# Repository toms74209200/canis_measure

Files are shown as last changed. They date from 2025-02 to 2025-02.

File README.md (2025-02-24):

<h1 style="text-align: center; margin-bottom: 4rem;">
<p style="font-size: 3rem;">Canis Measure</p>
Air Quality Monitor
</h1>

https://github.com/user-attachments/assets/3cffaff6-82ad-4612-b39e-0665e6a29b27

## Features

### Temperature and Humidity

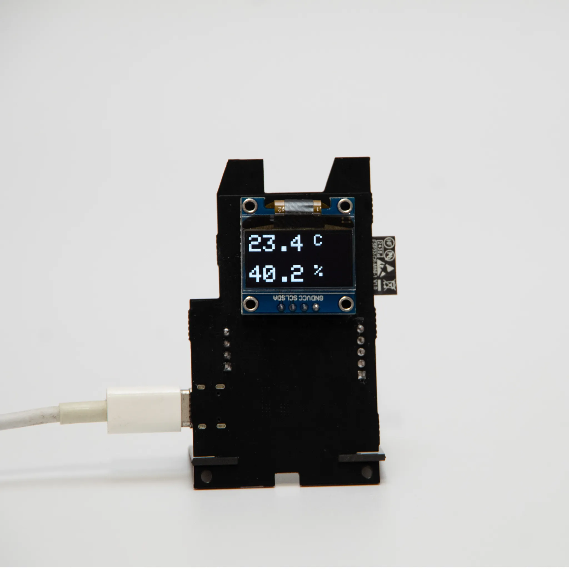
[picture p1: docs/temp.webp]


Temperature and humidity sensor is the SHT30.

### Pressure, CO2

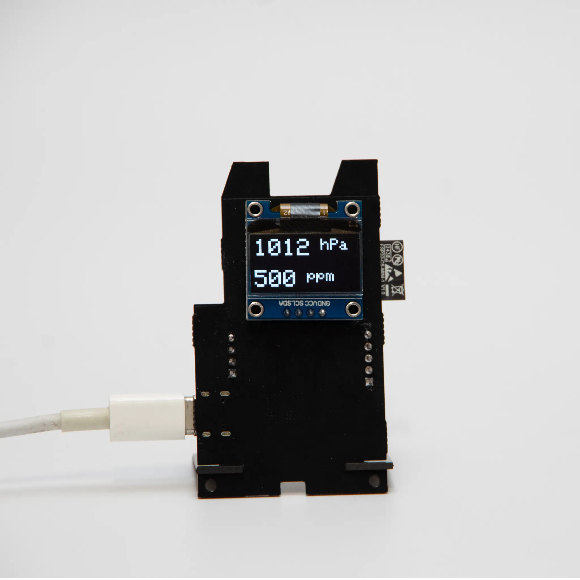
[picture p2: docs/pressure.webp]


Pressure sensor is the BMP280, CO2 sensor is the MH-Z19B.

## Specification

- [Espressif ESP32-C6](https://www.espressif.com/en/products/socs/esp32-c6)
- [Sensirion SHT30](https://sensirion.com/products/catalog/SHT30-DIS-B)
- [BOSCH BMP280](https://www.bosch-sensortec.com/products/environmental-sensors/pressure-sensors/bmp280/)
- [Winsen MH-Z19B](https://www.winsen-sensor.com/product/mh-z19b.html)
- 128x64 OLED display(SSD1306)

### Schematic

https://github.com/toms74209200/canis_measure/blob/master/pcb/EAQM-250201.pdf

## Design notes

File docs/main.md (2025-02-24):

<h1 style="text-align: center; margin-bottom: 4rem;">
<p style="font-size: 3rem;">Canis Measure</p>
Air Quality Monitor
</h1>

<video width="100%" height="auto" autoplay loop muted style="background-color: transparent;">
  <source src="canis_measure_face_movie.mp4" type="video/mp4">
  Your browser does not support the video tag.
</video>

## Features

### Temperature and Humidity



Temperature and humidity sensor is the SHT30.

### Pressure, CO2



Pressure sensor is the BMP280, CO2 sensor is the MH-Z19B.

## Specification

- [Espressif ESP32-C6](https://www.espressif.com/en/products/socs/esp32-c6)
- [Sensirion SHT30](https://sensirion.com/products/catalog/SHT30-DIS-B)
- [BOSCH BMP280](https://www.bosch-sensortec.com/products/environmental-sensors/pressure-sensors/bmp280/)
- [Winsen MH-Z19B](https://www.winsen-sensor.com/product/mh-z19b.html)
- 128x64 OLED display(SSD1306)

### Schematic

https://github.com/toms74209200/canis_measure/blob/master/pcb/EAQM-250201.pdf

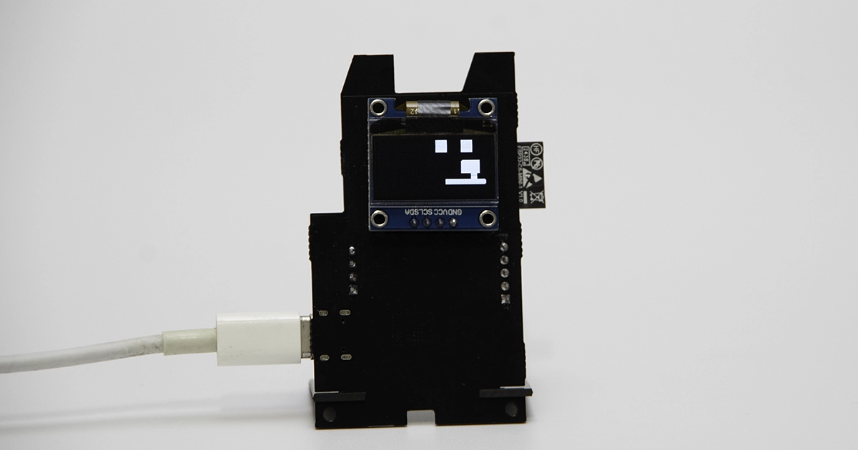
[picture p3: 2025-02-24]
docs/ogp.webp

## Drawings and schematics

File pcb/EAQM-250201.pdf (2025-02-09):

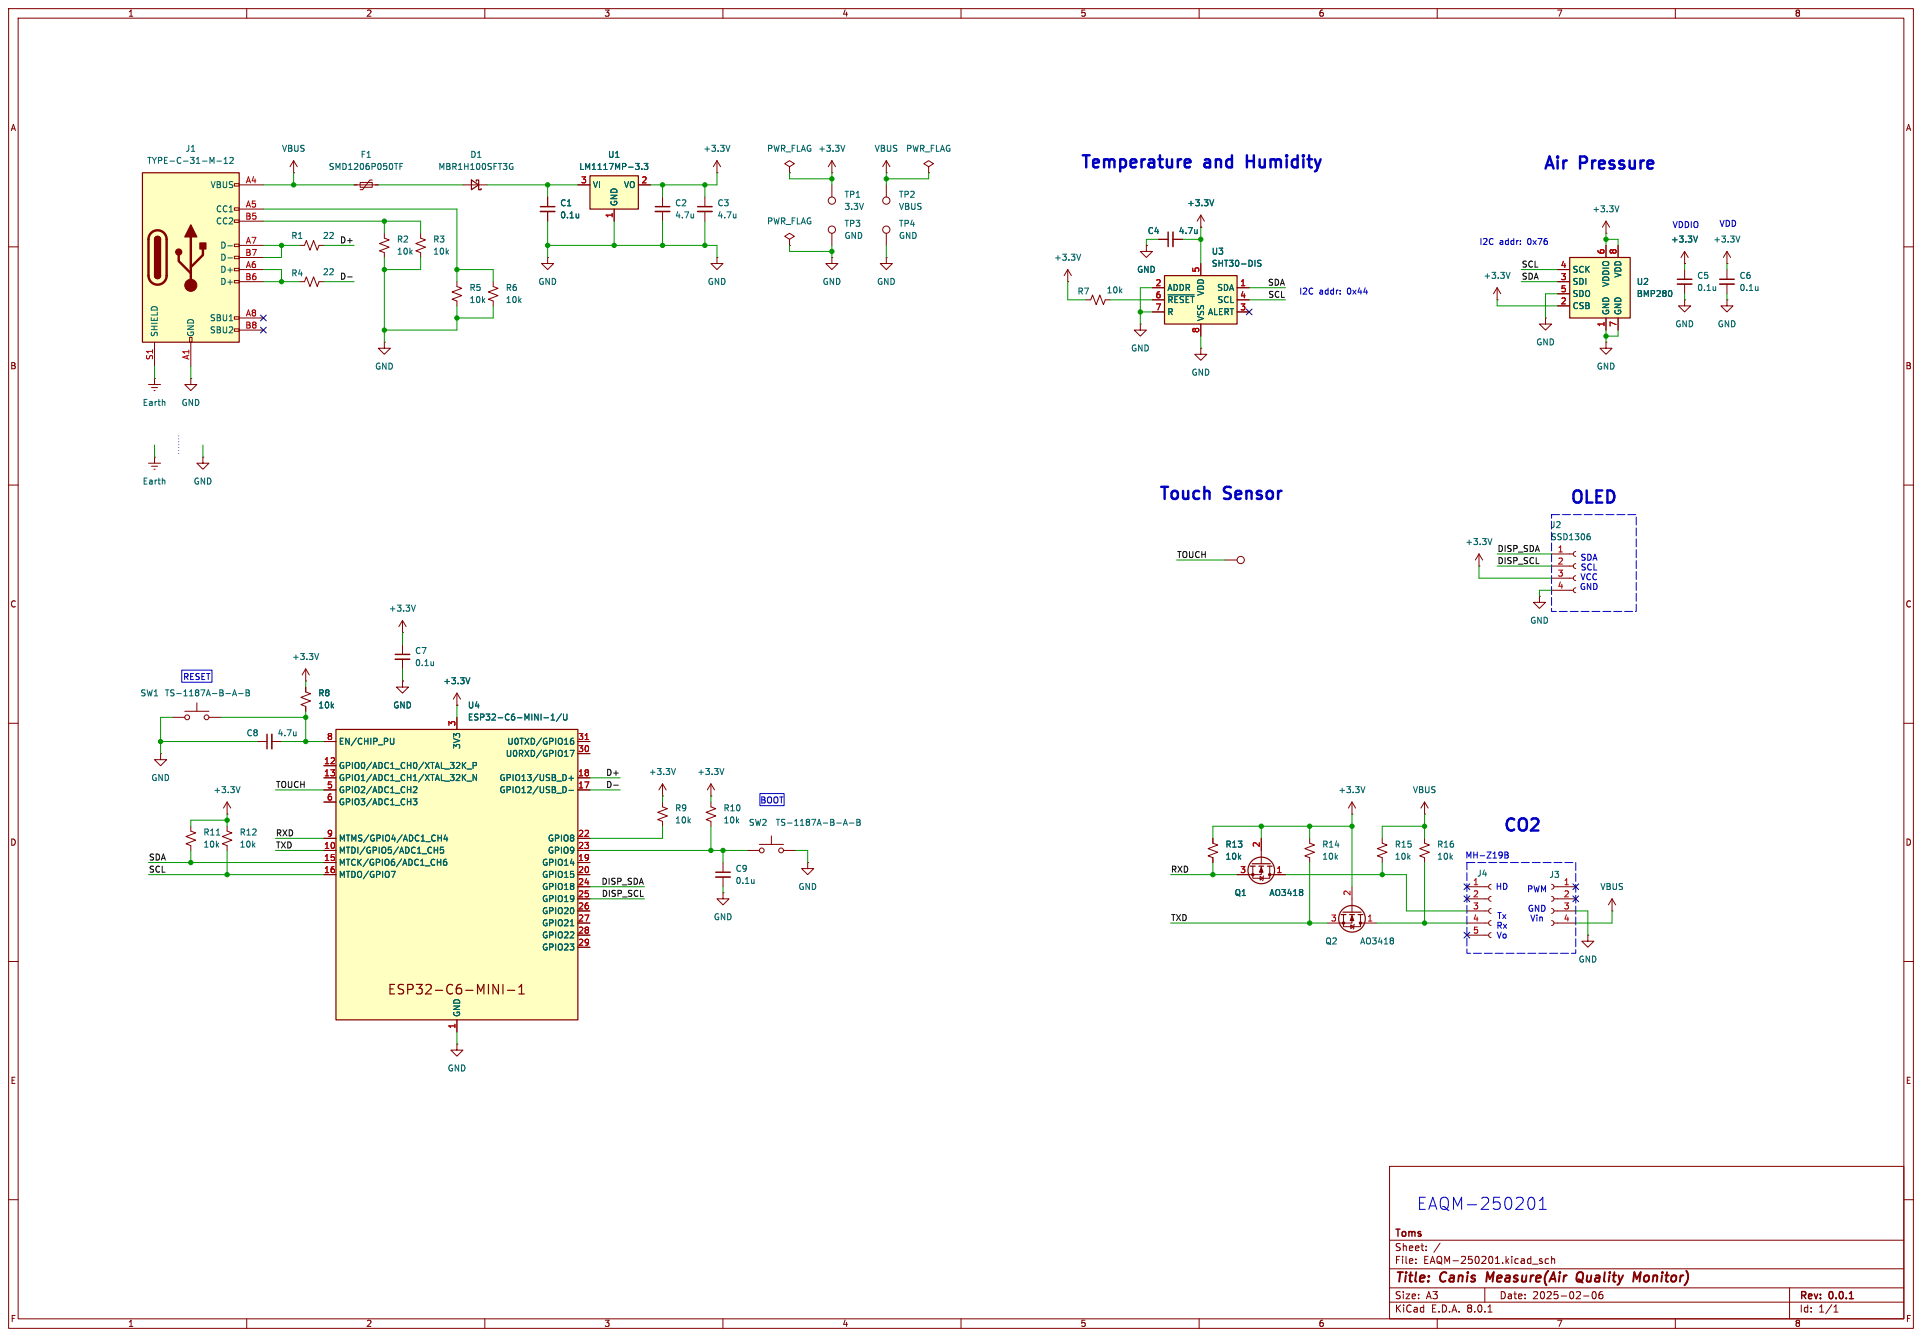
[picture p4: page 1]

1 VO 2 VI 3 U4ESP32-C6-MINI-1/U GND

1 CSB 2 SDI 3 SCK 4 SDO 5 VDDIO

SCL VCC GND OLED

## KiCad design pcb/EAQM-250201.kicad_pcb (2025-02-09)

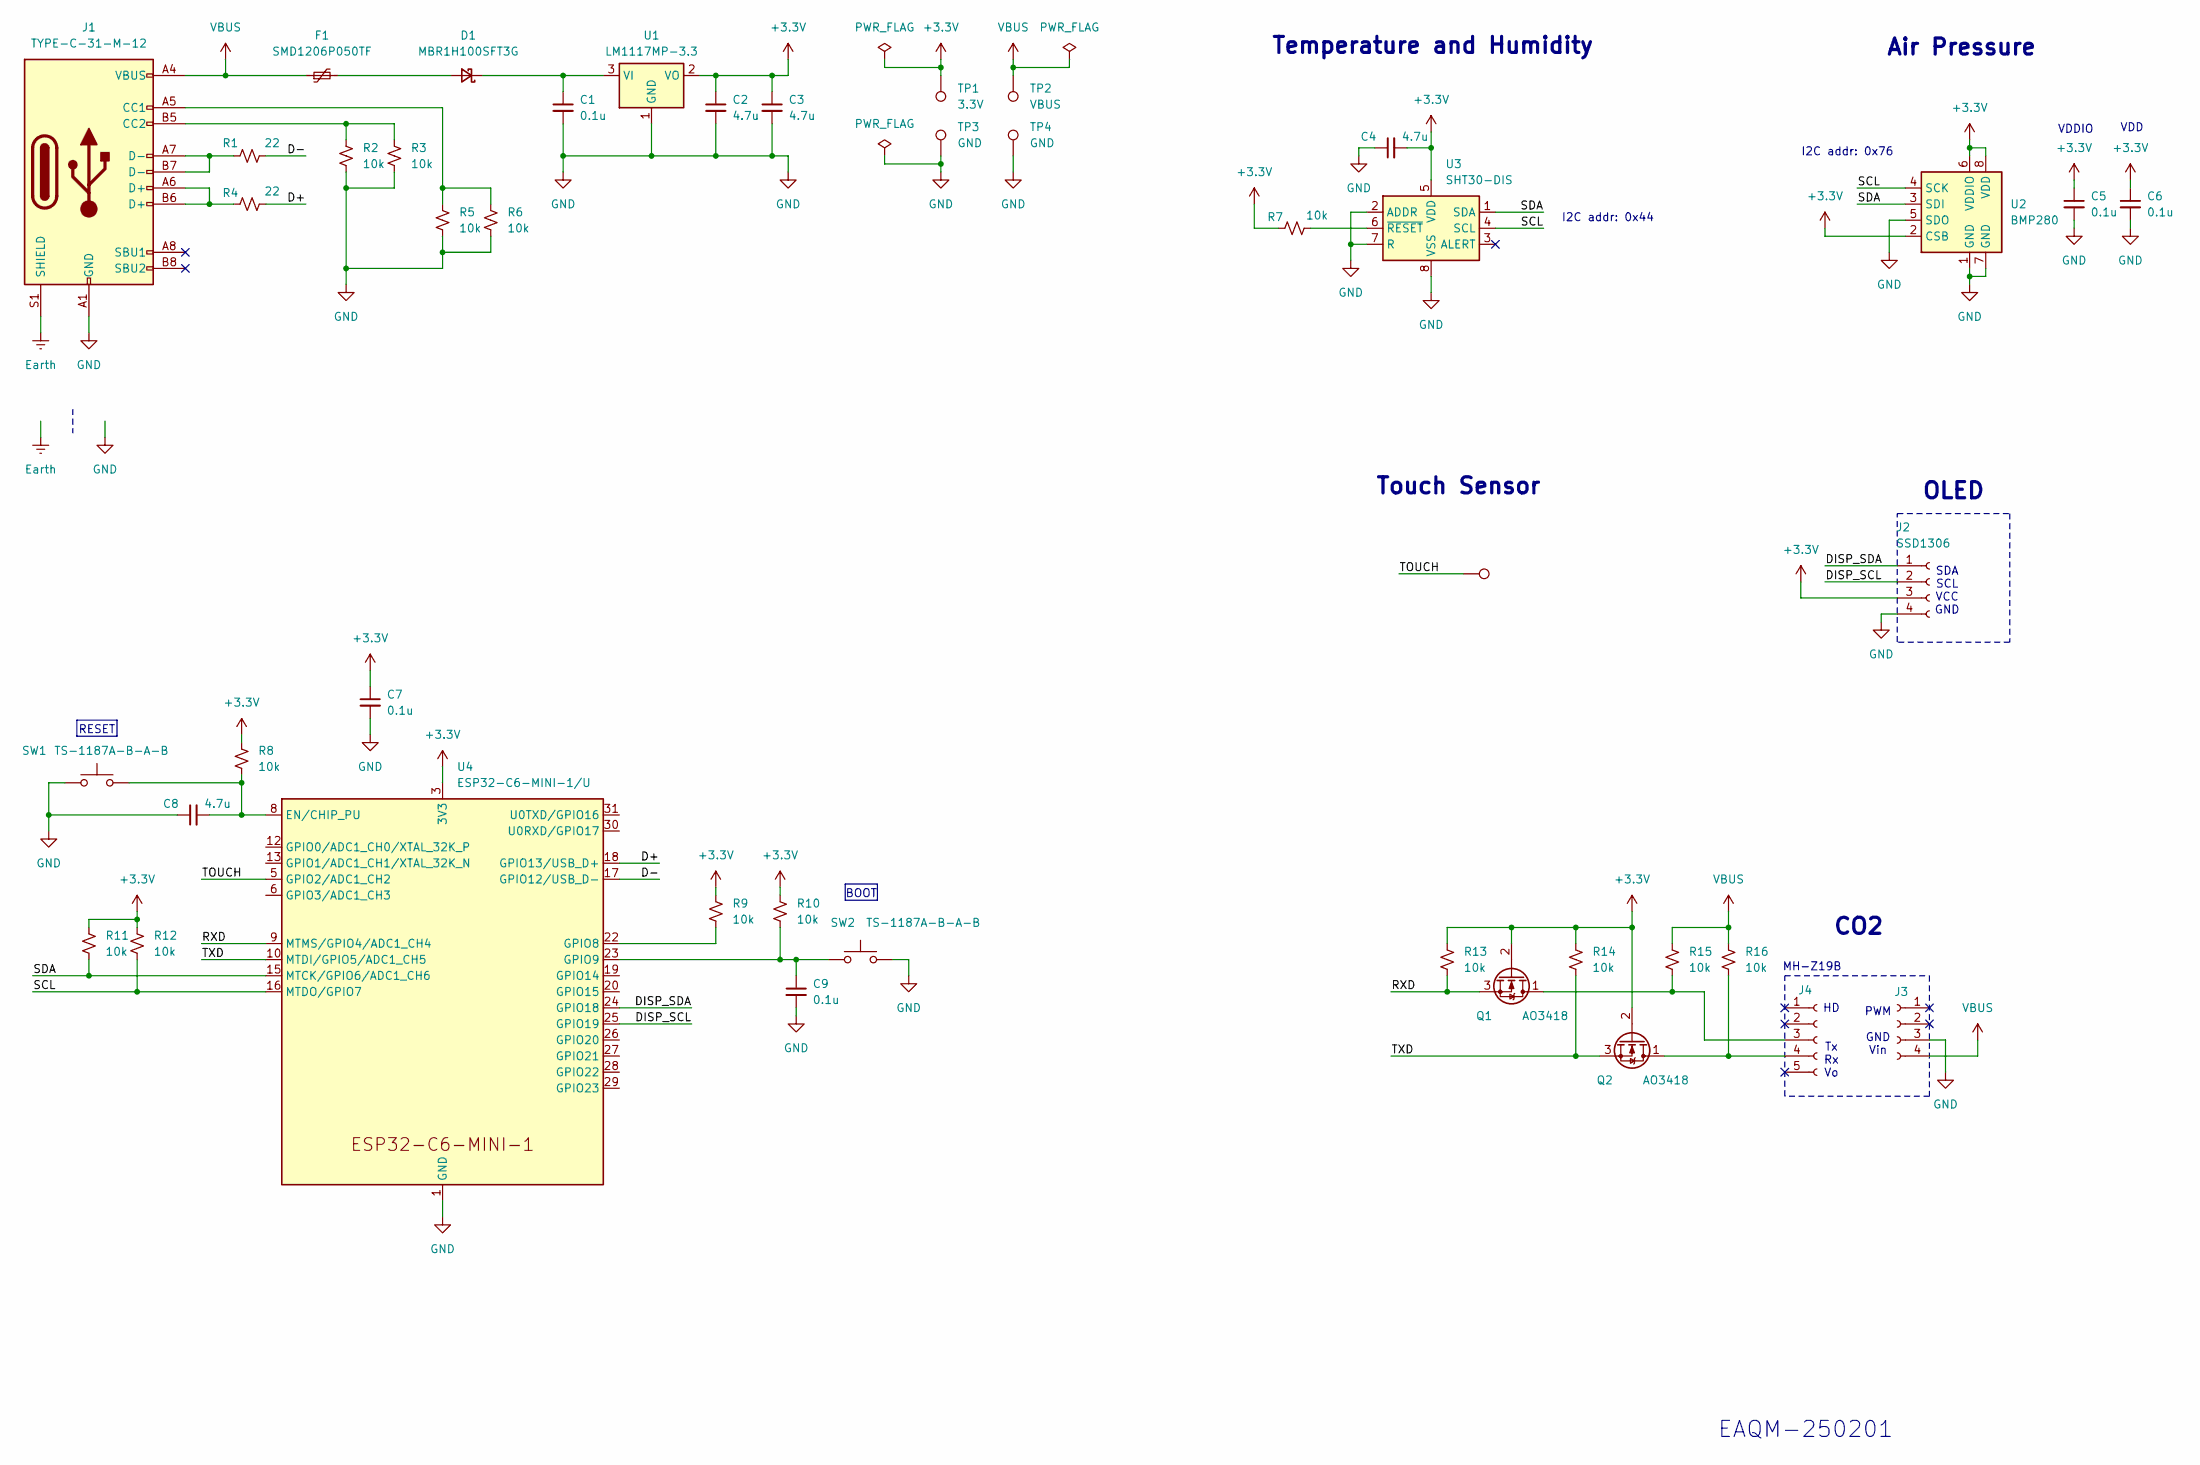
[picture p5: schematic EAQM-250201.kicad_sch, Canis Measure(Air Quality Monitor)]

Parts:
C1, C5, C6, C7, C9: 0.1u; C_0603_1608Metric
C2, C3, C4, C8: 4.7u; C_0603_1608Metric
D1: MBR1H100SFT3G; D_SOD-123F
F1: SMD1206P050TF; Fuse_1206_3216Metric
J1: TYPE-C-31-M-12; USB_C_Receptacle_Palconn_UTC16-G
J2: SSD1306; PinHeader_1x04_P2.54mm_Vertical
J3: Conn_01x04_Socket; PinHeader_1x04_P2.54mm_Vertical
J4: Conn_01x05_Socket; PinHeader_1x05_P2.54mm_Vertical
Q1, Q2: AO3418; SOT-23-3
R1, R4: 22; R_0603_1608Metric
R2, R3, R5, R6, R7, R8, R9, R10, R11, R12, R13, R14, R15, R16: 10k; R_0603_1608Metric
SW1, SW2: TS-1187A-B-A-B; SW_Push_1P1T_XKB_TS-1187A
TP1: 3.3V; TestPoint_Pad_D1.0mm
TP2: VBUS; TestPoint_Pad_D1.0mm
TP3, TP4: GND; TestPoint_Pad_D1.0mm
TP5: TestPoint
U1: LM1117MP-3.3; SOT-223-3_TabPin2
U2: BMP280; Bosch_LGA-8_2x2.5mm_P0.65mm_ClockwisePinNumbering
U3: SHT30-DIS; Sensirion_DFN-8-1EP_2.5x2.5mm_P0.5mm_EP1.1x1.7mm
U4: ESP32-C6-MINI-1/U; ESP32-C6-MINI-1

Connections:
+3.3V: C2.1, C3.1, C4.2, C5.1, C6.1, C7.1, J2.3, Q1.2 (G), Q2.2 (G), R7.1, R8.1, R9.1, R10.1, R11.1, R12.1, R13.1, R14.1, TP1.1, U1.2 (VO), U2.2 (CSB), U2.6 (VDDIO), U2.8 (VDD), U3.5 (VDD), U4.3 (3V3)
/D+: R4.2, U4.18 (GPIO13/USB_D+)
/D-: R1.2, U4.17 (GPIO12/USB_D-)
/DISP_SCL: J2.2, U4.25 (GPIO19)
/DISP_SDA: J2.1, U4.24 (GPIO18)
/RXD: Q1.3 (S), R13.2, U4.9 (MTMS/GPIO4/ADC1_CH4)
/SCL: R12.2, U2.4 (SCK), U3.4 (SCL), U4.16 (MTDO/GPIO7)
/SDA: R11.2, U2.3 (SDI), U3.1 (SDA), U4.15 (MTCK/GPIO6/ADC1_CH6)
/TOUCH: TP5.1, U4.5 (GPIO2/ADC1_CH2)
/TXD: Q2.3 (S), R14.2, U4.10 (MTDI/GPIO5/ADC1_CH5)
Earth: J1.S1 (SHIELD)
GND: C1.2, C2.2, C3.2, C4.1, C5.2, C6.2, C7.2, C8.1, C9.2, J1.A1 (GND), J1.A12 (GND), J1.B1 (GND), J1.B12 (GND), J2.4, J3.3, R2.2, R3.2, R5.2, R6.2, SW1.1, SW2.2, TP3.1, TP4.1, U1.1 (GND), U2.1 (GND), U2.5 (SDO), U2.7 (GND), U3.2 (ADDR), U3.7 (R), U3.8 (VSS), U3.9 (VSS), U4.1 (GND), U4.2 (GND), U4.11 (GND), U4.14 (GND), U4.36 (GND), U4.37 (GND), U4.38 (GND), U4.39 (GND), U4.40 (GND), U4.41 (GND), U4.42 (GND), U4.43 (GND), U4.44 (GND), U4.45 (GND), U4.46 (GND), U4.47 (GND), U4.48 (GND), U4.49 (GND), U4.50 (GND), U4.51 (GND), U4.52 (GND), U4.53 (GND)
unnamed: D1.2 (A), F1.2
unnamed: C1.1, D1.1 (K), U1.3 (VI)
unnamed: J1.A5 (CC1), R5.1, R6.1
unnamed: J1.B5 (CC2), R2.1, R3.1
unnamed: J1.A6 (D+), J1.B6 (D+), R4.1
unnamed: J1.A7 (D-), J1.B7 (D-), R1.1
unnamed: J4.3, Q1.1 (D), R15.2
unnamed: J4.4, Q2.1 (D), R16.2
unnamed: R7.2, U3.6 (~RESET)
unnamed: C8.2, R8.2, SW1.2, U4.8 (EN/CHIP_PU)
unnamed: R9.2, U4.22 (GPIO8)
unnamed: C9.1, R10.2, SW2.1, U4.23 (GPIO9)
VBUS: F1.1, J1.A4 (VBUS), J1.A9 (VBUS), J1.B4 (VBUS), J1.B9 (VBUS), J3.4, R15.1, R16.1, TP2.1

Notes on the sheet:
SDA SCL VCC GND
I2C addr: 0x44
Air Pressure
CO2
Temperature and Humidity
Touch Sensor
HD Tx Rx Vo
MH-Z19B
I2C addr: 0x76
BOOT
EAQM-250201
RESET
VDD
VDDIO
PWM GND Vin
OLED

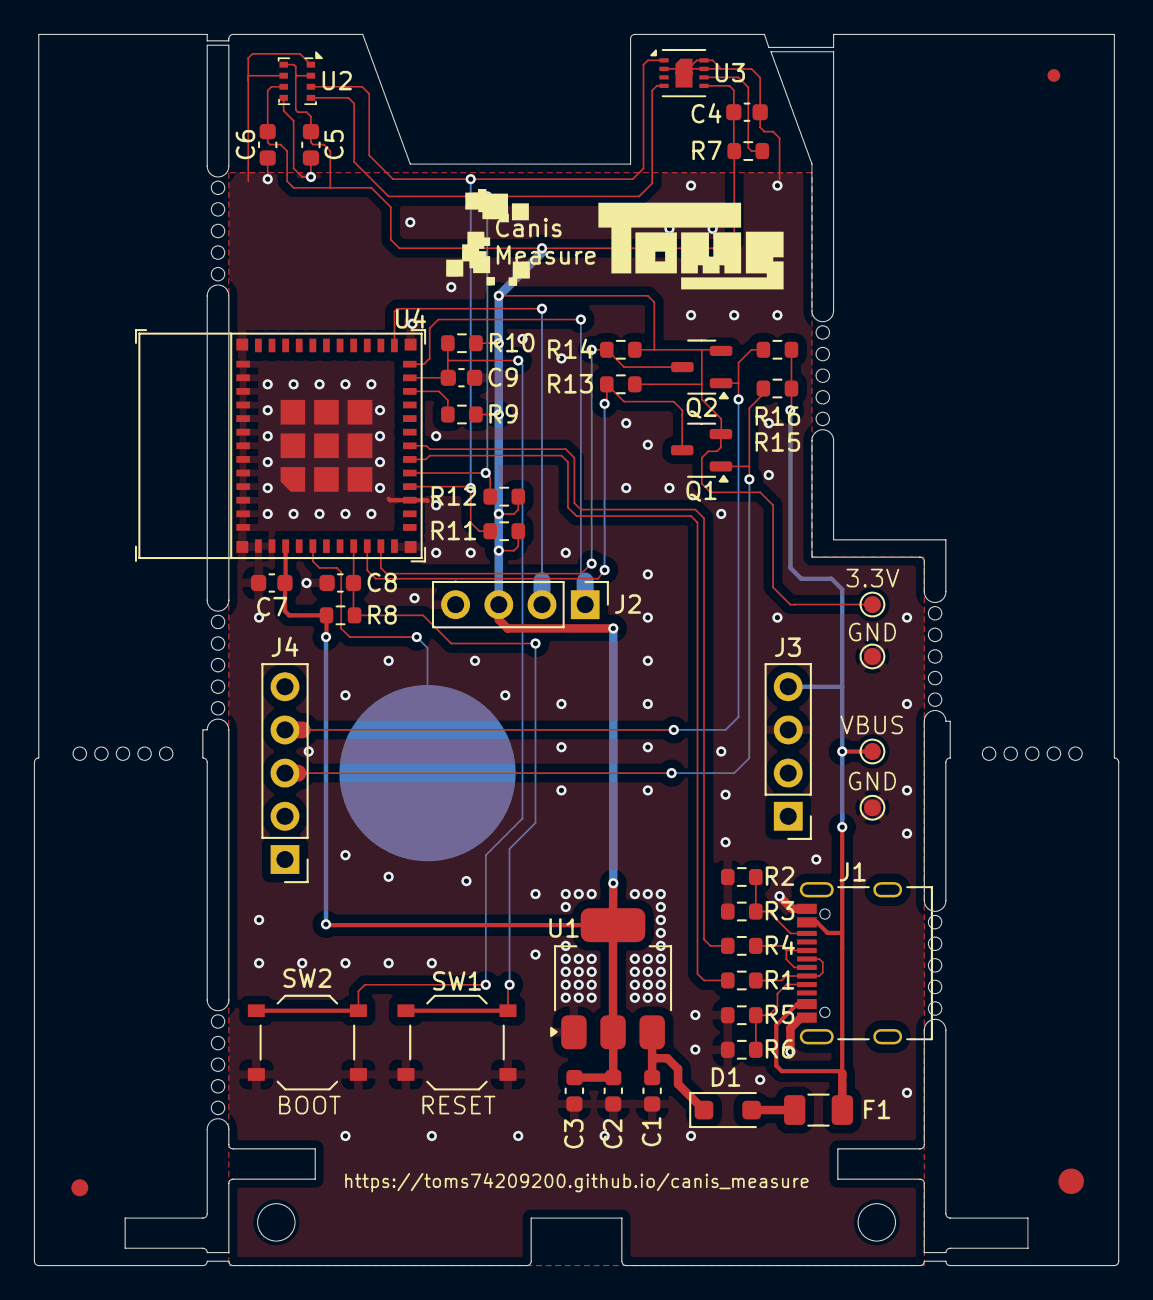
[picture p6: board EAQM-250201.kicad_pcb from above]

Board: 2 copper layers, 63.8 x 72.4 mm, 43 parts (0 on the bottom side), 23 nets.

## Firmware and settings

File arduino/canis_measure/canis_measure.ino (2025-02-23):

#define ARDUINO_STL

#include <memory>

#include <Adafruit_GFX.h>
#include <Adafruit_SSD1306.h>
#include <Wire.h>

#include "src/air_pressure/air_pressure.h"
#include "src/co2_sensor/co2_sensor.h"
#include "src/display/face.h"
#include "src/i2c_controller/i2c_controller.h"
#include "src/impl/i2c_controller_impl.h"
#include "src/impl/serial_controller_impl.h"
#include "src/temperature_humidity/temperature_humidity.h"

constexpr byte kSclPin = 7;
constexpr byte kSdaPin = 6;
constexpr byte kRxPin = 4;
constexpr byte kTxPin = 5;
constexpr byte kDisplaySclPin = 19;
constexpr byte kDisplaySdaPin = 18;

constexpr auto kScreenWidth = 128;
constexpr auto kScreenHeight = 64;
constexpr auto kOledReset =
    -1;  // Reset pin # (or -1 if sharing Arduino reset pin)
Adafruit_SSD1306 ssd1306(kScreenWidth, kScreenHeight, &Wire, kOledReset);

std::shared_ptr<i2c_controller::I2cController> i2c_controller_i;
std::unique_ptr<temperature_humidity::TemperatureHumidity> temp_humid;
std::unique_ptr<air_pressure::AirPressure> air_pressure_i;
std::unique_ptr<serial_controller::SerialController> serial_controller_i;
std::unique_ptr<co2::Co2Sensor> co2_sensor_i;

void BlinkEye() {
  ssd1306.clearDisplay();
  ssd1306.drawBitmap(0, 0, display::kFaceClose.data(), kScreenWidth,
                     kScreenHeight, 1);
  ssd1306.display();
  delay(100);
  ssd1306.clearDisplay();
  ssd1306.drawBitmap(0, 0, display::kFace.data(), kScreenWidth, kScreenHeight,
                     1);
  ssd1306.display();
}

void RetrieveAndDisplayTemperature() {
  auto [temperature, humidity] = temp_humid->GetTemperatureHumidity();

  ssd1306.clearDisplay();
  ssd1306.setCursor(0, 0);

  ssd1306.setTextSize(3);
  ssd1306.print(temperature, 1);
  ssd1306.setTextSize(2);
  ssd1306.print(" C");

  ssd1306.println();  // Margin
  ssd1306.setTextSize(3);
  ssd1306.println();

  ssd1306.print(humidity, 1);
  ssd1306.setTextSize(2);
  ssd1306.print(" %");

  ssd1306.display();
}

void RetrieveAndDisplayPressureAndCO2() {
  float pressure = air_pressure_i->GetAirPressure();
  int32_t co2_value = co2_sensor_i->GetCo2();

  ssd1306.clearDisplay();
  ssd1306.setCursor(0, 0);

  ssd1306.setTextSize(3);
  ssd1306.print(pressure, 0);
  ssd1306.setTextSize(2);
  ssd1306.print(" hPa");

  ssd1306.println();  // Margin
  ssd1306.setTextSize(3);
  ssd1306.println();

  ssd1306.print(co2_value);
  ssd1306.setTextSize(2);
  ssd1306.print(" ppm");

  ssd1306.display();
}

constexpr std::array<void (*)(), 2> kDisplayFunctions = {
    RetrieveAndDisplayTemperature, RetrieveAndDisplayPressureAndCO2};

void setup() {
  Wire.begin(kDisplaySdaPin, kDisplaySclPin);

  i2c_controller_i =
      std::make_shared<i2c_controller::I2cControllerImpl>(kSclPin, kSdaPin);
  i2c_controller_i->Init();

  temp_humid = std::make_unique<temperature_humidity::TemperatureHumidity>(
      i2c_controller_i);
  air_pressure_i =
      std::make_unique<air_pressure::AirPressure>(i2c_controller_i);
  serial_controller_i =
      std::make_unique<serial_controller::SerialControllerImpl>(kRxPin, kTxPin);
  serial_controller_i->Init();
  co2_sensor_i = std::make_unique<co2::Co2Sensor>(serial_controller_i.get());

  air_pressure_i->Init();
  co2_sensor_i->Init();

  if (!ssd1306.begin(SSD1306_SWITCHCAPVCC, 0x3C)) {
    while (1);
  }

  ssd1306.setRotation(2);
  ssd1306.clearDisplay();
  ssd1306.setTextSize(2);
  ssd1306.setTextColor(WHITE);

  ssd1306.drawBitmap(0, 0, display::kFace.data(), kScreenWidth, kScreenHeight,
                     1);

  ssd1306.display();

  for (int i = 0; i < 10; i++) {
    if (random(10) > 4) {
      BlinkEye();
    }
    device_sleep::DeviceSleep::For(
        std::chrono::duration_cast<std::chrono::milliseconds>(
            std::chrono::seconds(1)));
  }
}

void loop() {
  for (auto display_function : kDisplayFunctions) {
    display_function();
    device_sleep::DeviceSleep::For(
        std::chrono::duration_cast<std::chrono::milliseconds>(
            std::chrono::seconds(5)));
  }
}

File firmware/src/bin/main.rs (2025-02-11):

#![no_std]
#![no_main]

use esp_backtrace as _;
use esp_hal::timer::timg::TimerGroup;
use esp_hal::{clock::CpuClock, delay::Delay, main};

use log::info;

extern crate alloc;

#[main]
fn main() -> ! {
    // generator version: 0.2.2

    let config = esp_hal::Config::default().with_cpu_clock(CpuClock::max());
    let peripherals = esp_hal::init(config);

    esp_println::logger::init_logger_from_env();

    esp_alloc::heap_allocator!(72 * 1024);

    let timg0 = TimerGroup::new(peripherals.TIMG0);
    let _init = esp_wifi::init(
        timg0.timer0,
        esp_hal::rng::Rng::new(peripherals.RNG),
        peripherals.RADIO_CLK,
    )
    .unwrap();

    let delay = Delay::new();
    loop {
        info!("Hello world!");
        delay.delay_millis(500);
    }

    // for inspiration have a look at the examples at https://github.com/esp-rs/esp-hal/tree/v0.23.1/examples/src/bin
}

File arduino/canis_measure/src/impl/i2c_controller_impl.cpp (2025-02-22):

/**
 * @file i2c_controller_impl.cpp
 * @brief I2C controller implementation
 *
 * Copyright (c) 2025 toms74209200
 * This software is released under the MIT License.
 * http://opensource.org/licenses/mit-license.php
 */

#include "i2c_controller_impl.h"

i2c_controller::I2cControllerImpl::I2cControllerImpl(const uint8_t scl,
                                                     const uint8_t sda) {
  I2cControllerImpl::scl = scl;
  I2cControllerImpl::sda = sda;
}

void i2c_controller::I2cControllerImpl::Init() {
  digitalWrite(scl, HIGH);
  digitalWrite(sda, HIGH);
  pinMode(scl, OUTPUT);
  pinMode(sda, INPUT);
}

void i2c_controller::I2cControllerImpl::Start() {
  pinMode(sda, INPUT);
  pinMode(scl, OUTPUT);
  digitalWrite(scl, HIGH);
  digitalWrite(sda, HIGH);
  device_sleep::DeviceSleep::For(std::chrono::microseconds(kSclPeriodUs));

  digitalWrite(sda, LOW);
  pinMode(sda, OUTPUT);
  device_sleep::DeviceSleep::For(std::chrono::microseconds(kSclPeriodUs));

  digitalWrite(scl, LOW);
  device_sleep::DeviceSleep::For(std::chrono::microseconds(kSclPeriodUs));
}

void i2c_controller::I2cControllerImpl::Stop() {
  digitalWrite(sda, LOW);
  pinMode(sda, OUTPUT);
  device_sleep::DeviceSleep::For(std::chrono::microseconds(kSclPeriodUs));

  digitalWrite(scl, HIGH);
  device_sleep::DeviceSleep::For(std::chrono::microseconds(kSclPeriodUs));

  digitalWrite(sda, HIGH);
  device_sleep::DeviceSleep::For(std::chrono::microseconds(kSclPeriodUs));
}

bool i2c_controller::I2cControllerImpl::WriteByte(uint8_t data) {
  digitalWrite(sda, HIGH);
  pinMode(sda, OUTPUT);

  for (int i = 0; i < 8; i++) {
    digitalWrite(sda, (data & 0x80) >> 7);
    data <<= 1;
    device_sleep::DeviceSleep::For(std::chrono::microseconds(kClockPeriodUs));

    digitalWrite(scl, HIGH);
    device_sleep::DeviceSleep::For(std::chrono::microseconds(kClockPeriodUs));

    digitalWrite(scl, LOW);
    device_sleep::DeviceSleep::For(std::chrono::microseconds(kClockPeriodUs));
  }

  pinMode(sda, INPUT);
  digitalWrite(sda, HIGH);
  device_sleep::DeviceSleep::For(std::chrono::microseconds(kClockPeriodUs));

  digitalWrite(scl, HIGH);
  device_sleep::DeviceSleep::For(std::chrono::microseconds(kClockPeriodUs));
  bool ack = !digitalRead(sda);

  digitalWrite(scl, LOW);
  return ack;
}

uint8_t i2c_controller::I2cControllerImpl::ReadByte(bool sendAck) {
  uint8_t data = 0;

  pinMode(sda, INPUT);
  digitalWrite(sda, HIGH);

  for (int i = 0; i < 8; i++) {
    device_sleep::DeviceSleep::For(std::chrono::microseconds(kClockPeriodUs));

    digitalWrite(scl, HIGH);
    device_sleep::DeviceSleep::For(std::chrono::microseconds(kClockPeriodUs));
    data = (data << 1) | digitalRead(sda);

    digitalWrite(scl, LOW);
    device_sleep::DeviceSleep::For(std::chrono::microseconds(kClockPeriodUs));
  }

  digitalWrite(sda, !sendAck);
  pinMode(sda, OUTPUT);
  device_sleep::DeviceSleep::For(std::chrono::microseconds(kClockPeriodUs));

  digitalWrite(scl, HIGH);
  device_sleep::DeviceSleep::For(std::chrono::microseconds(kClockPeriodUs));

  digitalWrite(scl, LOW);
  pinMode(sda, INPUT);
  digitalWrite(sda, HIGH);

  return data;
}

void i2c_controller::I2cControllerImpl::Write(const uint8_t address,
                                              std::vector<uint8_t> data) {
  Start();
  WriteByte(address << 1);

  for (const auto& d : data) {
    WriteByte(d);
  }

  Stop();
}

std::vector<uint8_t> i2c_controller::I2cControllerImpl::Read(
    const uint8_t address, const int_fast32_t size) {
  std::vector<uint8_t> data;

  Start();
  WriteByte((address << 1) | 0x01);

  for (int i = 0; i < size; i++) {
    data.push_back(ReadByte(i < size - 1));
  }

  Stop();
  return data;
}

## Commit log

2025-02-08 :sparkles: Add schematic
    [EAQM-250201.kicad_sch]
2025-02-09 :sparkles: Update schematic
    [EAQM-250201.kicad_sch]
2025-02-09 :sparkles: Add PCB artwork
    [EAQM-250201.kicad_pcb]
2025-02-13 :hammer: Add DevContainer settings for Arduino
2025-02-13 :hammer: Add editor settings for Arduino
2025-02-13 :sparkles: Add temperature sensor
2025-02-15 :sparkles: Add implementation for I2C controller
2025-02-15 :sparkles: Add Air Pressure sensor
2025-02-18 :sparkles: Add CO2 sensor
2025-02-19 :sparkles: Update I2C controller
2025-02-22 :bug: Update air pressure sensor
    [air_pressure.cpp, air_pressure.h]
2025-02-22 :art: Clean I2C controller
2025-02-22 :sparkles: Update CO2 sensor
2025-02-23 :sparkles: Add Arduino main
